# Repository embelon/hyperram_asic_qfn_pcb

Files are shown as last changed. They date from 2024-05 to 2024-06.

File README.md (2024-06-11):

# hyperram_asic_qfn_pcb
Test PCB for CARAVEL ASIC (in QFP package) manufactured by efables.com in Open Source Shuttles to check HyperRAM memory controller IP connected to RISC-V through Wishbone bus.

HyperRAM controller was submitted in [GFMPW-0 (5V)](https://platform.efabless.com/projects/1667) and [MPW-8](https://platform.efabless.com/projects/1826).

HyperRAM controller IP was created to work with Cypress S27KL0641:
https://github.com/embelon/wb_hyperram

### Images
top
bottom

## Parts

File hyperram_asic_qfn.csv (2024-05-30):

Reference | Value | Datasheet | Footprint | Qty | DNP
C1,C2,C3,C4,C5,C6,C7,C8,C9,C10,C15,C18,C19,C20,C21 | 100n | ~ | Capacitor_SMD:C_0402_1005Metric_Pad0.74x0.62mm_HandSolder | 15
C11,C12,C16,C17,C23 | 1u 16v | ~ | Capacitor_SMD:C_0805_2012Metric_Pad1.18x1.45mm_HandSolder | 5
C13,C14 | 4u7 16v | ~ | Capacitor_SMD:C_0805_2012Metric_Pad1.18x1.45mm_HandSolder | 2
C22,C24 | 22u 25v | ~ | Capacitor_SMD:C_0805_2012Metric_Pad1.18x1.45mm_HandSolder | 2
D1,D2 | LED | ~ | LED_SMD:LED_0805_2012Metric_Pad1.15x1.40mm_HandSolder | 2
IC1 | W25Q32JVSSIQ_TR | https://www.winbond.com/resource-files/w25q32jv%20spi%20revc%2008302016.pdf | hyperram_asic_qfn:SOIC127P790X216-8N | 1
IC2 | S27KL0641DABHI020 | http://www.cypress.com/file/183506/download | hyperram_asic_qfn:BGA24C100P5X5_600X800X100 | 1
IC5 | LP5907MFX-3.3_NOPB | https://datasheet.datasheetarchive.com/originals/distributors/Datasheets-SFU2/DSASFU100037200.pdf | hyperram_asic_qfn:SOT95P280X145-5N | 1
IC6 | MCP1824T-1802E_OT | https://datasheet.datasheetarchive.com/originals/distributors/SFDatasheet-4/sf-00090041.pdf | hyperram_asic_qfn:SOT95P270X145-5N | 1
J1 | USB_B_Micro | ~ | hyperram_asic_qfn:UJ2MIBHGSMTTR | 1
J2 | Conn_02x06_Odd_Even | ~ | Connector_PinHeader_2.54mm:PinHeader_2x06_P2.54mm_Vertical | 1
J3,J4 | 1156915 | http://www.phoenixcontact.com/gb/produkte/1156915 | hyperram_asic_qfn:1156915 | 2
J7 | Conn_02x10_Odd_Even | ~ | Connector_PinHeader_2.54mm:PinHeader_2x10_P2.54mm_Vertical | 1
R1,R2 | 220 | ~ | Resistor_SMD:R_0603_1608Metric | 2
R3 | 22 | ~ | Resistor_SMD:R_0603_1608Metric | 1
R4 | 2k2 | ~ | Resistor_SMD:R_0603_1608Metric | 1
R5 | 0 | ~ | Resistor_SMD:R_0603_1608Metric | 1
R6 | NC | ~ | Resistor_SMD:R_0603_1608Metric | 1
RN1,RN2,RN3 | CAY16-22R0F4LF | ~ | hyperram_asic_qfn:CAY16000J4LF | 3
TP1 | 5V | ~ | TestPoint:TestPoint_Pad_D1.0mm | 1
TP2 | CLK | ~ | TestPoint:TestPoint_Pad_D1.0mm | 1
TP3 | 3V3 | ~ | TestPoint:TestPoint_Pad_D1.0mm | 1
TP4 | 1V8 | ~ | TestPoint:TestPoint_Pad_D1.0mm | 1
TP5 | TestPoint | ~ | TestPoint:TestPoint_Pad_D1.0mm | 1
TP6 | GND | ~ | TestPoint:TestPoint_Pad_D1.0mm | 1
TP7 | VCC | ~ | TestPoint:TestPoint_Pad_D1.0mm | 1
U1 | CARAVEL_QFN |  | Package_DFN_QFN:QFN-64-1EP_9x9mm_P0.5mm_EP7.65x7.65mm | 1
Y1 | SG5032CAN_20.000000M-TJGA3 | https://datasheet.datasheetarchive.com/originals/distributors/Datasheets_SAMA/ce4a807d57040677cd35953a6e54e0c8.pdf | hyperram_asic_qfn:SG5032CAN20000000MTJGA3 | 1

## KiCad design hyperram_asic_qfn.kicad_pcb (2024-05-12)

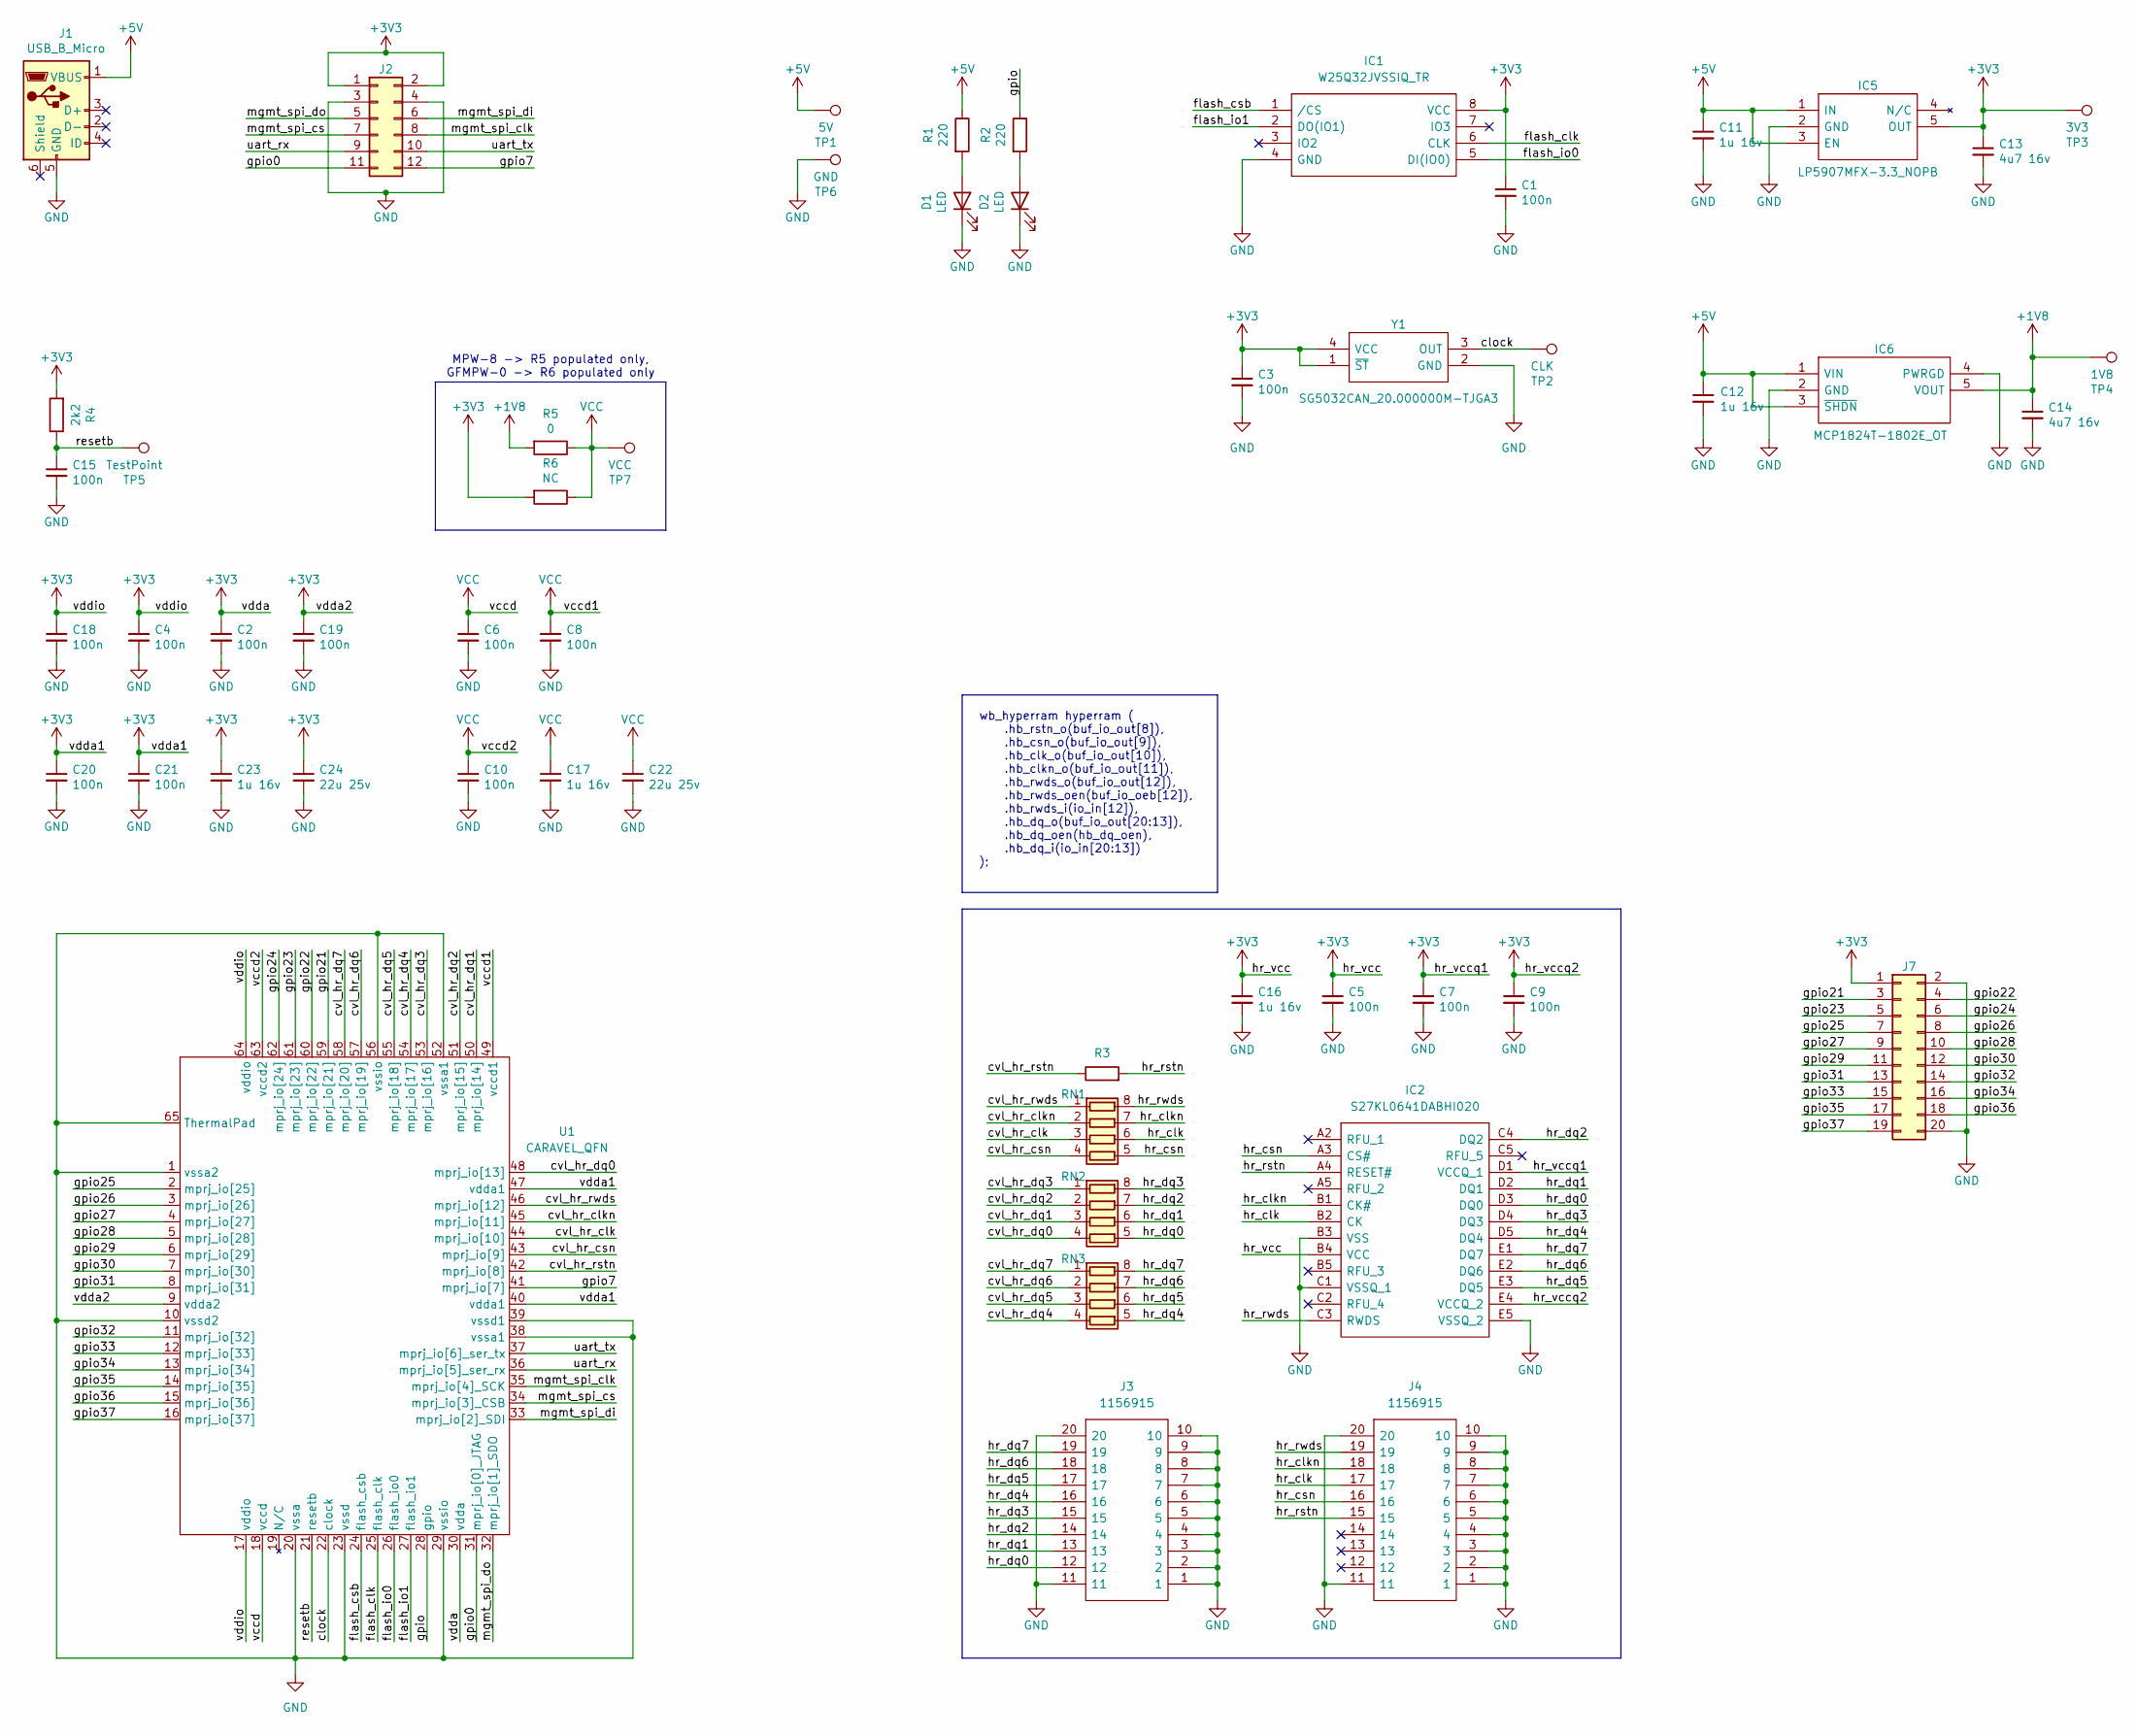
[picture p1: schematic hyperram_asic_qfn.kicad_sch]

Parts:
C1, C2, C3, C4, C5, C6, C7, C8, C9, C10, C15, C19, C20, C21: 100n; C_0402_1005Metric_Pad0.74x0.62mm_HandSolder; Part CGA3E2X7R1H223K080AA
C11, C12, C16, C17, C23: 1u 16v; C_0805_2012Metric_Pad1.18x1.45mm_HandSolder; Part CL10A105KO8NNNC
C13, C14: 4u7 16v; C_0805_2012Metric_Pad1.18x1.45mm_HandSolder; Part CC0603KRX5R7BB475
C18: 100n; C_0402_1005Metric_Pad0.74x0.62mm_HandSolder; Part CL10A105KO8NNNC
C22, C24: 22u 25v; C_0805_2012Metric_Pad1.18x1.45mm_HandSolder; Part CL10A105KO8NNNC
D1, D2: LED; LED_0805_2012Metric_Pad1.15x1.40mm_HandSolder; Part LS Q976-NR-1
IC1: W25Q32JVSSIQ_TR; SOIC127P790X216-8N; Mouser Part Number 454-W25Q32JVSSIQTR
IC2: S27KL0641DABHI020; BGA24C100P5X5_600X800X100; Manufacturer_Part_Number S27KL0641DABHI020; Mouser Part Number 727-S27KL0641DABHI02
IC5: LP5907MFX-3.3_NOPB; SOT95P280X145-5N; Mouser Part Number 595-LP5907MFX-3.3NPB
IC6: MCP1824T-1802E_OT; SOT95P270X145-5N; Mouser Part Number 579-MCP1824T-1802EOT
J1: USB_B_Micro; UJ2MIBHGSMTTR; Part 105017-0001
J2: Conn_02x06_Odd_Even; PinHeader_2x06_P2.54mm_Vertical
J3, J4: 1156915; Mouser Part Number 651-1156915
J7: Conn_02x10_Odd_Even; PinHeader_2x10_P2.54mm_Vertical
R1, R2: 220; R_0603_1608Metric; Part ‎RC0603JR-07100RL‎
R3: R; R_0603_1608Metric
R4: 2k2; R_0603_1608Metric; Part ‎RC0603JR-07100RL‎
R5: 0; R_0603_1608Metric; Part ‎RC0603JR-07100RL‎
R6: NC; R_0603_1608Metric; Part ‎RC0603JR-07100RL‎
RN1, RN2, RN3: CAY16-22R0F4LF; CAY16000J4LF
TP1: 5V; TestPoint_Pad_D1.0mm
TP2: CLK; TestPoint_Pad_D1.0mm
TP3: 3V3; TestPoint_Pad_D1.0mm
TP4: 1V8; TestPoint_Pad_D1.0mm
TP5: TestPoint; TestPoint_Pad_D1.0mm
TP6: GND; TestPoint_Pad_D1.0mm
TP7: VCC; TestPoint_Pad_D1.0mm
U1: CARAVEL_QFN; QFN-64-1EP_9x9mm_P0.5mm_EP7.65x7.65mm
Y1: SG5032CAN_20.000000M-TJGA3; SG5032CAN20000000MTJGA3; Mouser Part Number 732-5032CAN20.0TJGA3

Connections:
+1V8: C14.1, IC6.5 (VOUT), R5.2, TP4.1
+3V3: C1.1, C2.1, C3.1, C4.1, C5.1, C7.1, C9.1, C13.1, C16.1, C18.1, C19.1, C20.1, C21.1, C23.1, C24.1, IC1.8 (VCC), IC2.B4 (VCC), IC2.D1 (VCCQ_1), IC2.E4 (VCCQ_2), IC5.5 (OUT), J2.1, J2.2, J7.1, R4.2, R6.2, TP3.1, U1.9 (vdda2), U1.17 (vddio), U1.30 (vdda), U1.40 (vdda1), U1.47 (vdda1), U1.64 (vddio), Y1.1 (~ST), Y1.4 (VCC)
+5V: C11.1, C12.1, IC5.1 (IN), IC5.3 (EN), IC6.1 (VIN), IC6.3 (~SHDN), J1.1 (VBUS), R1.1, TP1.1
/clock: TP2.1, U1.22 (clock), Y1.3 (OUT)
/cvl_hr_clk: RN1.3 (R3.1), U1.44 (mprj_io[10])
/cvl_hr_clkn: RN1.2 (R2.1), U1.45 (mprj_io[11])
/cvl_hr_csn: RN1.4 (R4.1), U1.43 (mprj_io[9])
/cvl_hr_dq0: RN2.4 (R4.1), U1.48 (mprj_io[13])
/cvl_hr_dq1: RN2.3 (R3.1), U1.50 (mprj_io[14])
/cvl_hr_dq2: RN2.2 (R2.1), U1.51 (mprj_io[15])
/cvl_hr_dq3: RN2.1 (R1.1), U1.53 (mprj_io[16])
/cvl_hr_dq4: RN3.4 (R4.1), U1.54 (mprj_io[17])
/cvl_hr_dq5: RN3.3 (R3.1), U1.55 (mprj_io[18])
/cvl_hr_dq6: RN3.2 (R2.1), U1.57 (mprj_io[19])
/cvl_hr_dq7: RN3.1 (R1.1), U1.58 (mprj_io[20])
/cvl_hr_rstn: R3.1, U1.42 (mprj_io[8])
/cvl_hr_rwds: RN1.1 (R1.1), U1.46 (mprj_io[12])
/flash_clk: IC1.6 (CLK), U1.25 (flash_clk)
/flash_csb: IC1.1 (/CS), U1.24 (flash_csb)
/flash_io0: IC1.5 (DI(IO0)), U1.26 (flash_io0)
/flash_io1: IC1.2 (DO(IO1)), U1.27 (flash_io1)
/gpio: R2.1, U1.28 (gpio)
/gpio0: J2.11, U1.31 (mprj_io[0]_JTAG)
/gpio7: J2.12, U1.41 (mprj_io[7])
/gpio21: J7.3, U1.59 (mprj_io[21])
/gpio22: J7.4, U1.60 (mprj_io[22])
/gpio23: J7.5, U1.61 (mprj_io[23])
/gpio24: J7.6, U1.62 (mprj_io[24])
/gpio25: J7.7, U1.2 (mprj_io[25])
/gpio26: J7.8, U1.3 (mprj_io[26])
/gpio27: J7.9, U1.4 (mprj_io[27])
/gpio28: J7.10, U1.5 (mprj_io[28])
/gpio29: J7.11, U1.6 (mprj_io[29])
/gpio30: J7.12, U1.7 (mprj_io[30])
/gpio31: J7.13, U1.8 (mprj_io[31])
/gpio32: J7.14, U1.11 (mprj_io[32])
/gpio33: J7.15, U1.12 (mprj_io[33])
/gpio34: J7.16, U1.13 (mprj_io[34])
/gpio35: J7.17, U1.14 (mprj_io[35])
/gpio36: J7.18, U1.15 (mprj_io[36])
/gpio37: J7.19, U1.16 (mprj_io[37])
/hr_clk: IC2.B2 (CK), J4.17, RN1.6 (R3.2)
/hr_clkn: IC2.B1 (CK#), J4.18, RN1.7 (R2.2)
/hr_csn: IC2.A3 (CS#), J4.16, RN1.5 (R4.2)
/hr_dq0: IC2.D3 (DQ0), J3.12, RN2.5 (R4.2)
/hr_dq1: IC2.D2 (DQ1), J3.13, RN2.6 (R3.2)
/hr_dq2: IC2.C4 (DQ2), J3.14, RN2.7 (R2.2)
/hr_dq3: IC2.D4 (DQ3), J3.15, RN2.8 (R1.2)
/hr_dq4: IC2.D5 (DQ4), J3.16, RN3.5 (R4.2)
/hr_dq5: IC2.E3 (DQ5), J3.17, RN3.6 (R3.2)
/hr_dq6: IC2.E2 (DQ6), J3.18, RN3.7 (R2.2)
/hr_dq7: IC2.E1 (DQ7), J3.19, RN3.8 (R1.2)
/hr_rstn: IC2.A4 (RESET#), J4.15, R3.2
/hr_rwds: IC2.C3 (RWDS), J4.19, RN1.8 (R1.2)
/mgmt_spi_clk: J2.8, U1.35 (mprj_io[4]_SCK)
/mgmt_spi_cs: J2.7, U1.34 (mprj_io[3]_CSB)
/mgmt_spi_di: J2.6, U1.33 (mprj_io[2]_SDI)
/mgmt_spi_do: J2.5, U1.32 (mprj_io[1]_SDO)
/resetb: C15.1, R4.1, TP5.1, U1.21 (resetb)
/uart_rx: J2.9, U1.36 (mprj_io[5]_ser_rx)
/uart_tx: J2.10, U1.37 (mprj_io[6]_ser_tx)
GND: C1.2, C2.2, C3.2, C4.2, C5.2, C6.2, C7.2, C8.2, C9.2, C10.2, C11.2, C12.2, C13.2, C14.2, C15.2, C16.2, C17.2, C18.2, C19.2, C20.2, C21.2, C22.2, C23.2, C24.2, D1.1 (K), D2.1 (K), IC1.4 (GND), IC2.B3 (VSS), IC2.C1 (VSSQ_1), IC2.E5 (VSSQ_2), IC5.2 (GND), IC6.2 (GND), IC6.4 (PWRGD), J1.5 (GND), J2.3, J2.4, J3.1, J3.2, J3.3, J3.4, J3.5, J3.6, J3.7, J3.8, J3.9, J3.10, J3.11, J3.20, J4.1, J4.2, J4.3, J4.4, J4.5, J4.6, J4.7, J4.8, J4.9, J4.10, J4.11, J4.20, J7.2, J7.20, TP6.1, U1.1 (vssa2), U1.10 (vssd2), U1.20 (vssa), U1.23 (vssd), U1.29 (vssio), U1.38 (vssa1), U1.39 (vssd1), U1.52 (vssa1), U1.56 (vssio), U1.65 (ThermalPad), Y1.2 (GND)
unnamed: D1.2 (A), R1.2
unnamed: D2.2 (A), R2.2
VCC: C6.1, C8.1, C10.1, C17.1, C22.1, R5.1, R6.1, TP7.1, U1.18 (vccd), U1.49 (vccd1), U1.63 (vccd2)

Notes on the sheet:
MPW-8 -> R5 populated only, GFMPW-0 -> R6 populated only
wb_hyperram hyperram ( .hb_rstn_o(buf_io_out[8]), .hb_csn_o(buf_io_out[9]), .hb_clk_o(buf_io_out[10]), .hb_clkn_o(buf_io_out[11]), .hb_rwds_o(buf_io_out[12]), .hb_rwds_oen(buf_io_oeb[12]), .hb_rwds_i(io_in[12]), .hb_dq_o(buf_io_out[20:13]), .hb_dq_oen(hb_dq_oen), .hb_dq_i(io_in[20:13]) );

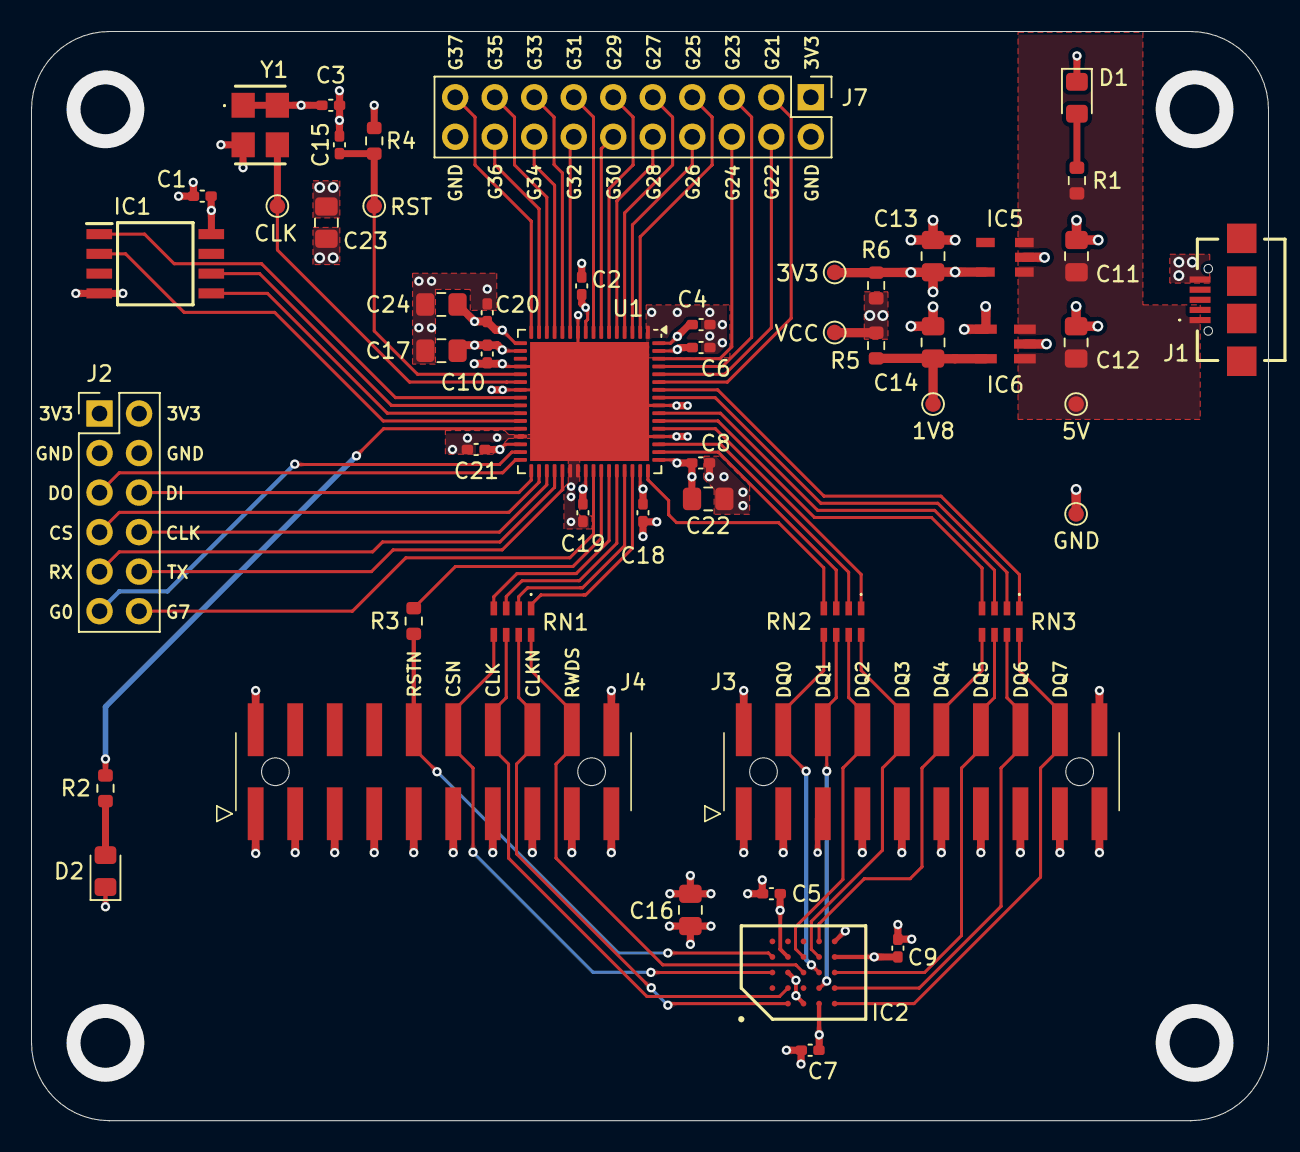
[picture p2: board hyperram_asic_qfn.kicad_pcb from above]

Board: 4 copper layers, 79.5 x 70.0 mm, 53 parts (0 on the bottom side), 65 nets.

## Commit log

2024-04-26 Updated schematic with symbol CARAVEL WLCSP changed to CARAVEL QFN
    [hyperram_asic_qfn.kicad_pcb, hyperram_asic_qfn.kicad_sch]
2024-04-27 Added GPIO header. Cleaned up ERC warnings and errors in schematic.
    [hyperram_asic_qfn.kicad_sch]
2024-04-28 Updated schematic: resistors instead of jumpers to select VCC, integrated two smaller headers into one bigger.
    [hyperram_asic_qfn.kicad_sch]
2024-04-28 Fixed package assignments and library. Reordered signals to easy routing pcb.
    [hyperram_asic_qfn.kicad_sch]
2024-04-28 First try on component placement and routing.
    [hyperram_asic_qfn.kicad_pcb]
2024-05-05 Changed design constraints to adjust to PCBWay and JLCPCB abilities for Standard 4-layer boards.
2024-05-05 Removed duplicated LDOs in BGA packages.
    [hyperram_asic_qfn.kicad_sch]
2024-05-05 Adjusted placement of some components and started routing tracks between ASIC and HyperRAM chip.
    [hyperram_asic_qfn.kicad_pcb]
2024-05-07 First try for routing digital signals (DSPI, GPIOs, CLK, RST)
    [hyperram_asic_qfn.kicad_pcb]
2024-05-09 Improved placement. Routed all digital signals.
    [hyperram_asic_qfn.kicad_pcb]
2024-05-11 All signals routed, polygons filled.
    [hyperram_asic_qfn.kicad_pcb]
2024-05-11 Updated USB footprint, Through Hole to SMD
2024-05-11 Fixed PCB DRC issues - prepared for PCBWay, track/spacing 4/4mils, min hole size 0.25mm
    [hyperram_asic_qfn.kicad_pcb]
2024-05-11 Updated Testpoints description to voltage values.
    [hyperram_asic_qfn.kicad_sch]
2024-05-11 Adjusted References on Silkscreen for better readability
    [hyperram_asic_qfn.kicad_pcb]
2024-05-12 Fixed position of USB connector
    [hyperram_asic_qfn.kicad_pcb]
2024-05-30 Added missing resistance value for R3
    [hyperram_asic_qfn.kicad_sch]
2024-05-30 Created BOM
    [hyperram_asic_qfn.csv]
2024-06-11 Added render action for PCB
